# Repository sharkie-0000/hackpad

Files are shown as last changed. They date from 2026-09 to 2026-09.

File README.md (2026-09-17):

# My Hackpad

hey! this is my hackpad :)

i created this project to practice pcb design, electronics and firmware and at the same time create something i will be able to use on my desk.

the concept of this project is quite easy – small macropad with custom keys, rotary encoder and custom pcb. you can use it to set up your shortcuts, macros, control devices, etc.

## What is it

my hackpad has:

- 9 mechanical switches
- 1 rotary encoder
- XIAO RP2040
- 9 diodes
- 4 mounting holes
- custom PCB
- 3D printed case

i have built almost everything on my own so i would be able to understand the entire process of creating such device.

## Pictures / Files

### 3D Model
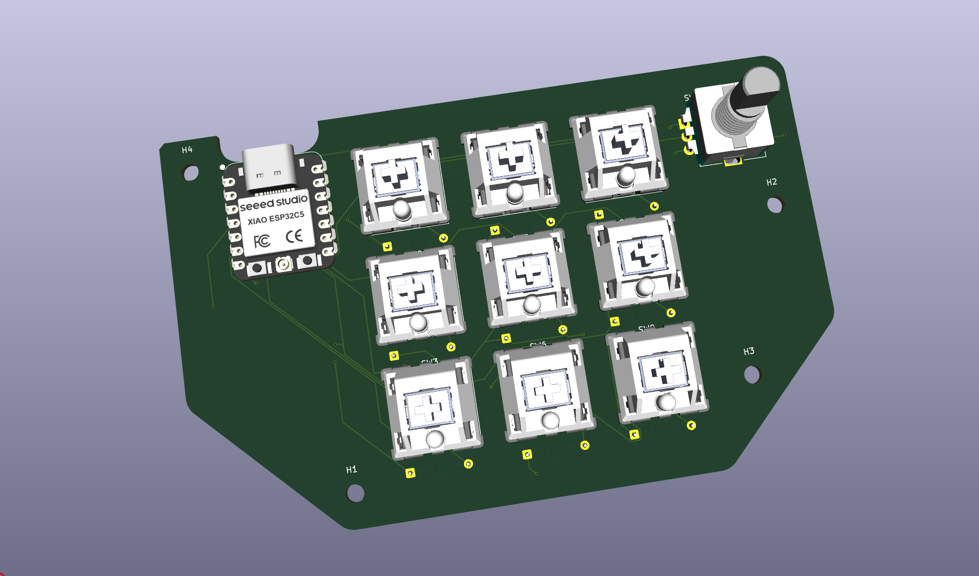
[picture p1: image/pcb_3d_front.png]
PCB 3D Front

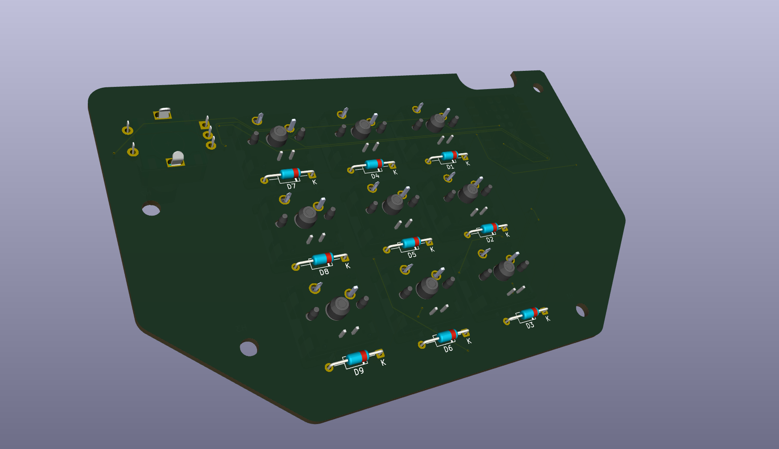
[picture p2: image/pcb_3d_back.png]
PCB 3D Back


### Circuit / Schematic
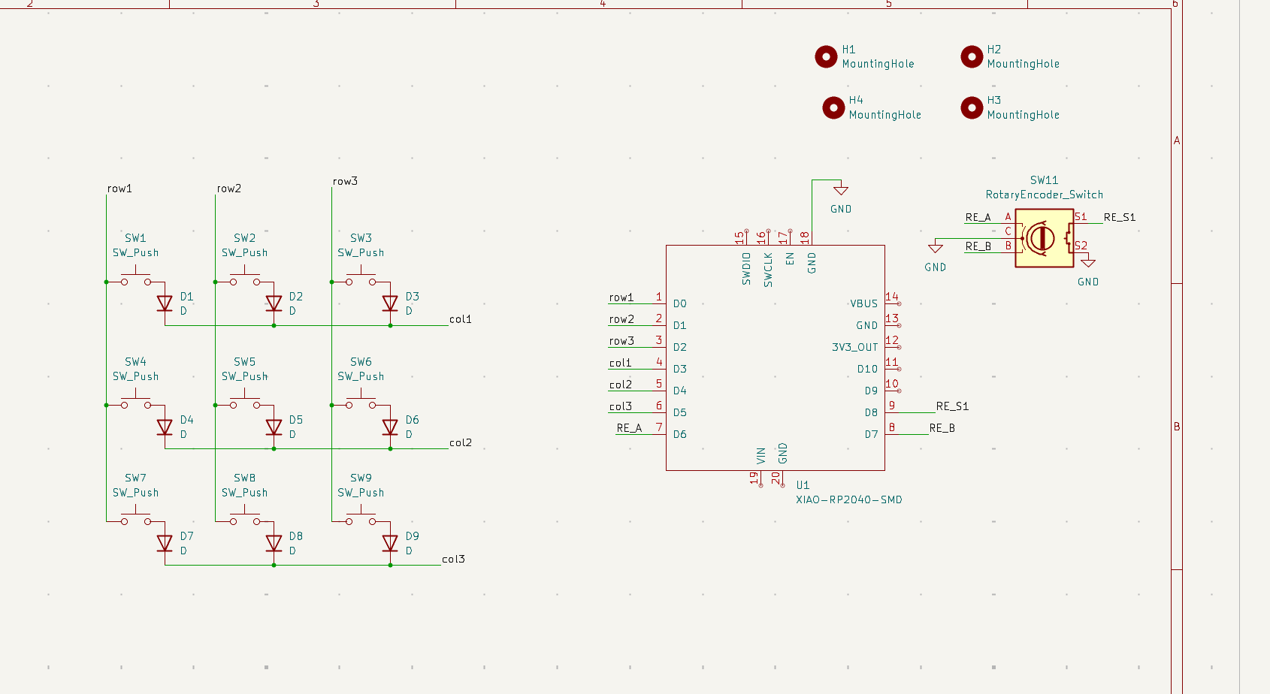
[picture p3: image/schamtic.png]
Schematic


### PCB Circuit
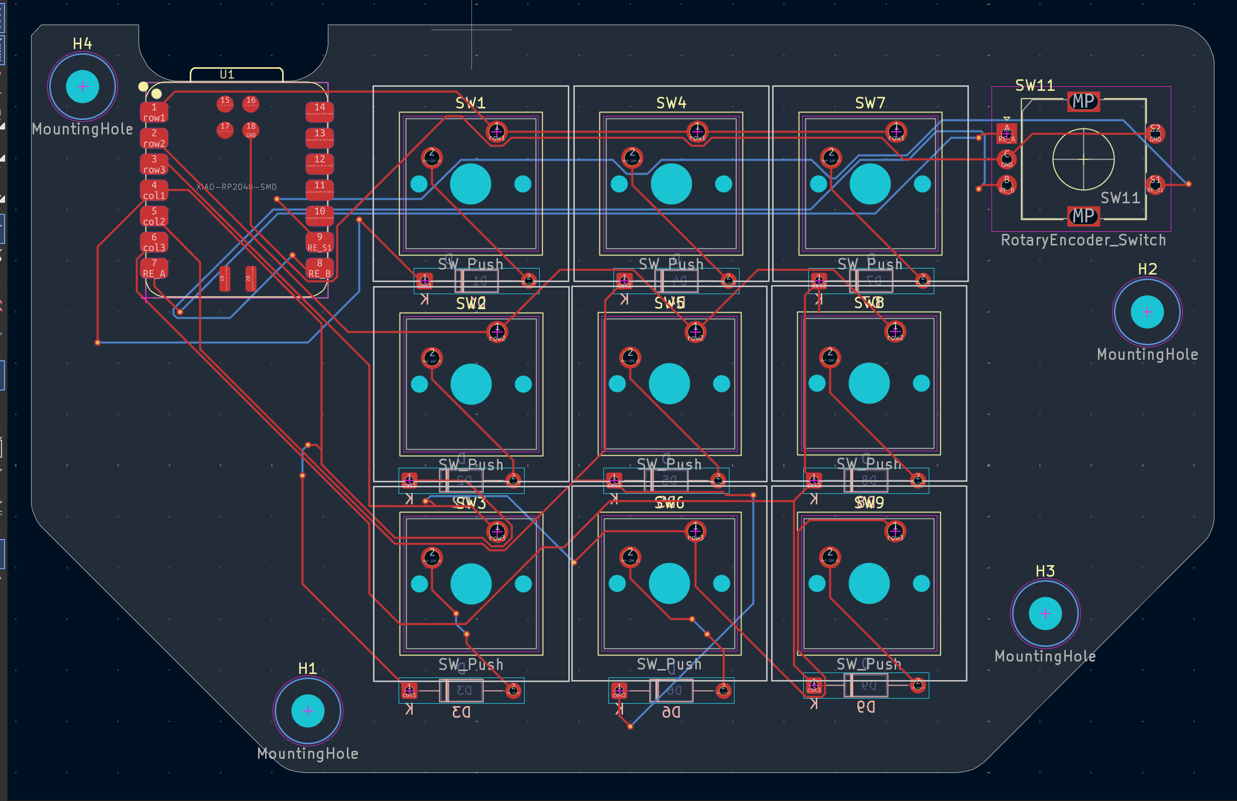
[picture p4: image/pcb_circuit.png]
PCB Circuit


## Bill of Materials (BOM)

here is the list of parts needed for the hackpad:

Here are the parts used for this build:

| Item | Quantity | Price | Link |
| --- | ---: | ---: | --- |
| Seeed Studio XIAO RP2040 Development Board | 1 | ₹589 | [Robu / RoboCraze](https://robocraze.com/products/seeed-studio-xiao-rp2040-development-board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) |
| Rotary Encoder (PEC12R-4225F-S0024) | 1 | ₹159 | [LionCircuits](https://www.lioncircuits.com/parts/PEC12R-4225F-S0024) |
| Cherry MX Mechanical Switches (Pack of 10) | 9 | ₹350 | [Cosmic Byte](https://www.thecosmicbyte.com/product/cherry-mx-mechancial-5-pin-switches-compatible-with-hot-swappable-keyboards-pack-of-10/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) |
| Spongebob Artisan Keycaps | 9 | ₹0 (already have) | [Meckeys](https://meckeys.com/shop/accessories/keyboard-accessories/keycaps/artisan-keycaps/spongebob-artisan-keycaps/) |
| PCB Fabrication | 1 | ₹720 | [JLCPCB](https://jlcpcb.com) |
| Diodes | 9 | ₹149 | [Diode](https://rees52.com/products/100pcs-diode-assortment-kit-rectifier-diode-kit-8-values-diy-electronic-diode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) |
| 3D Printed Case | 1 | — | — |
| **Total Cost** | | **₹1,967** | |

## Assembly Steps

1. Put the PCB on the bottom plate and fix it by using **M3 Screws**.
2. Fasten the upper portion of the box to the bottom plate with the help of **Glue**.
3. The use of M3 screws is **optional**. You can also fasten the whole box with the help of glue.
4. Ensure that everything is properly aligned.

## Why did i build this?

because i wanted to learn to create a circuit board myself rather than always purchasing them off the shelf. a custom macropad seemed to be an engaging way of learning and having something useful that i could use at my desk.

also built for Hack Club because it allowed me to engage in the process of building the circuit board from scratch without letting it stay only in my head.

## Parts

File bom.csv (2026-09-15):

Item | Price | Link
Seeed Studio XIAO RP2040 Development Board | ₹589 | https://robocraze.com/products/seeed-studio-xiao-rp2040-development-board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
Rotary Encoder (PEC12R-4225F-S0024) | ₹159 | https://www.lioncircuits.com/parts/PEC12R-4225F-S0024
Cherry MX Mechanical Switches (Pack of 10) | ₹350 | https://www.thecosmicbyte.com/product/cherry-mx-mechancial-5-pin-switches-compatible-with-hot-swappable-keyboards-pack-of-10/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
Spongebob Artisan Keycaps | ₹699 | https://meckeys.com/shop/accessories/keyboard-accessories/keycaps/artisan-keycaps/spongebob-artisan-keycaps/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
100pcs Diode Assortment Kit | ₹149.00 | "https://rees52.com/products/100pcs-diode-assortment-kit-rectifier-diode-kit-8-values-diy-electronic-diode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"
PCB Fabrication | USD 8.5 | https://jlcpcb.com

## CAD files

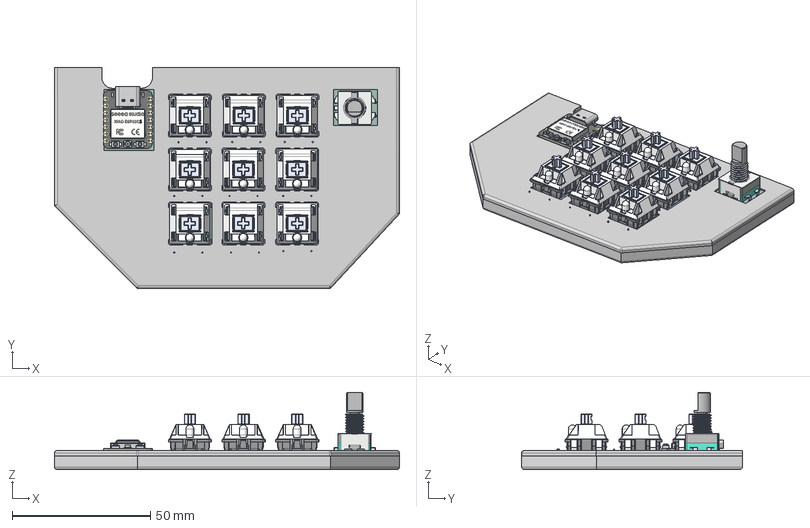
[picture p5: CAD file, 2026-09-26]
cad/hackpad-assembled.step
125.0 x 80.0 x 28.0 mm

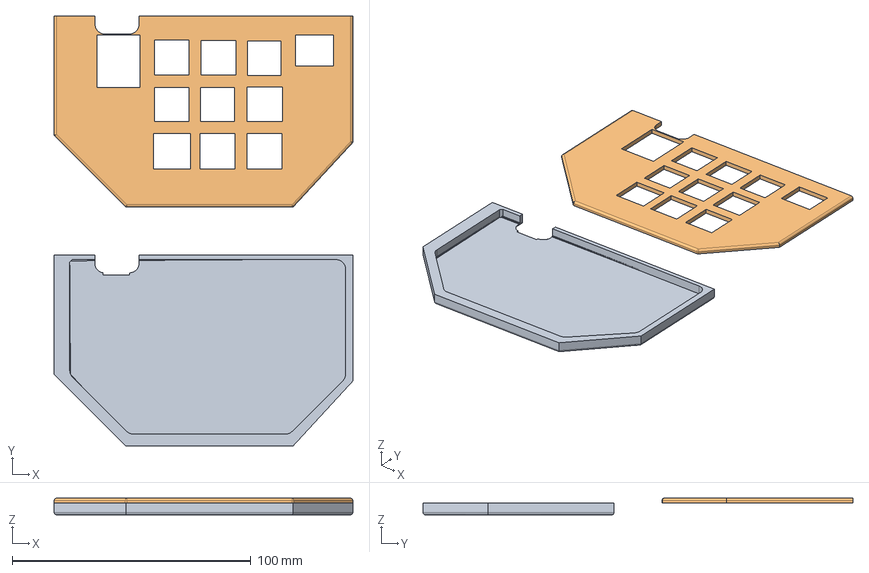
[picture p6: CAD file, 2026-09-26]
cad/hackpad-printable.step
125.0 x 180.0 x 7.00 mm

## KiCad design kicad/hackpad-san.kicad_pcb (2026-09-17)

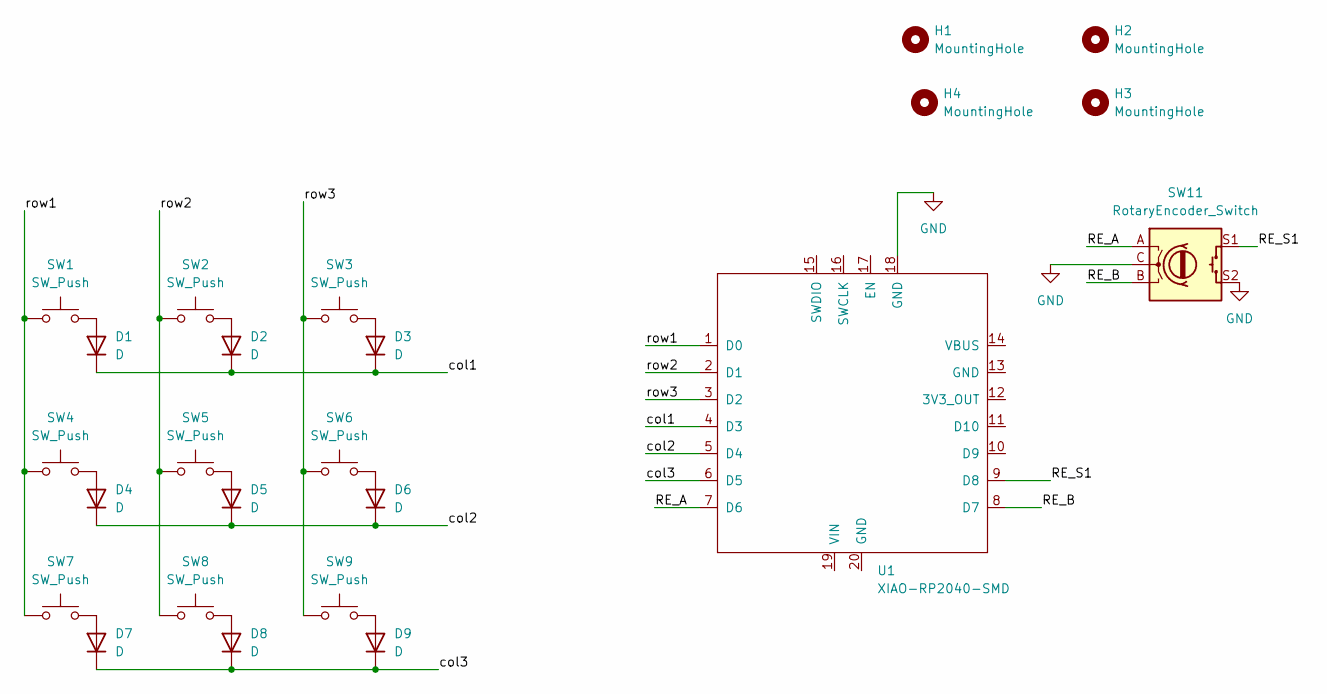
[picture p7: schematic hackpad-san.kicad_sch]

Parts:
D1, D2, D3, D4, D5, D6, D7, D8, D9: D; D_DO-35_SOD27_P10.16mm_Horizontal
H1, H2, H3, H4: MountingHole; MountingHole_3.2mm_M3
SW1, SW2, SW3, SW4, SW5, SW6, SW7, SW8, SW9: SW_Push; SW_Cherry_MX_1.00u_PCB
SW11: RotaryEncoder_Switch; RotaryEncoder_Alps_EC11E-Switch_Vertical_H20mm
U1: XIAO-RP2040-SMD

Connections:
/RE_A: SW11.A, U1.7 (D6)
/RE_B: SW11.B, U1.8 (D7)
/RE_S1: SW11.S1, U1.9 (D8)
/col1: D1.1 (K), D2.1 (K), D3.1 (K), U1.4 (D3)
/col2: D4.1 (K), D5.1 (K), D6.1 (K), U1.5 (D4)
/col3: D7.1 (K), D8.1 (K), D9.1 (K), U1.6 (D5)
/row1: SW1.1, SW4.1, SW7.1, U1.1 (D0)
/row2: SW2.1, SW5.1, SW8.1, U1.2 (D1)
/row3: SW3.1, SW6.1, SW9.1, U1.3 (D2)
GND: SW11.C, SW11.S2, U1.18 (GND)
unnamed: D1.2 (A), SW1.2
unnamed: D2.2 (A), SW2.2
unnamed: D3.2 (A), SW3.2
unnamed: D4.2 (A), SW4.2
unnamed: D5.2 (A), SW5.2
unnamed: D6.2 (A), SW6.2
unnamed: D7.2 (A), SW7.2
unnamed: D8.2 (A), SW8.2
unnamed: D9.2 (A), SW9.2

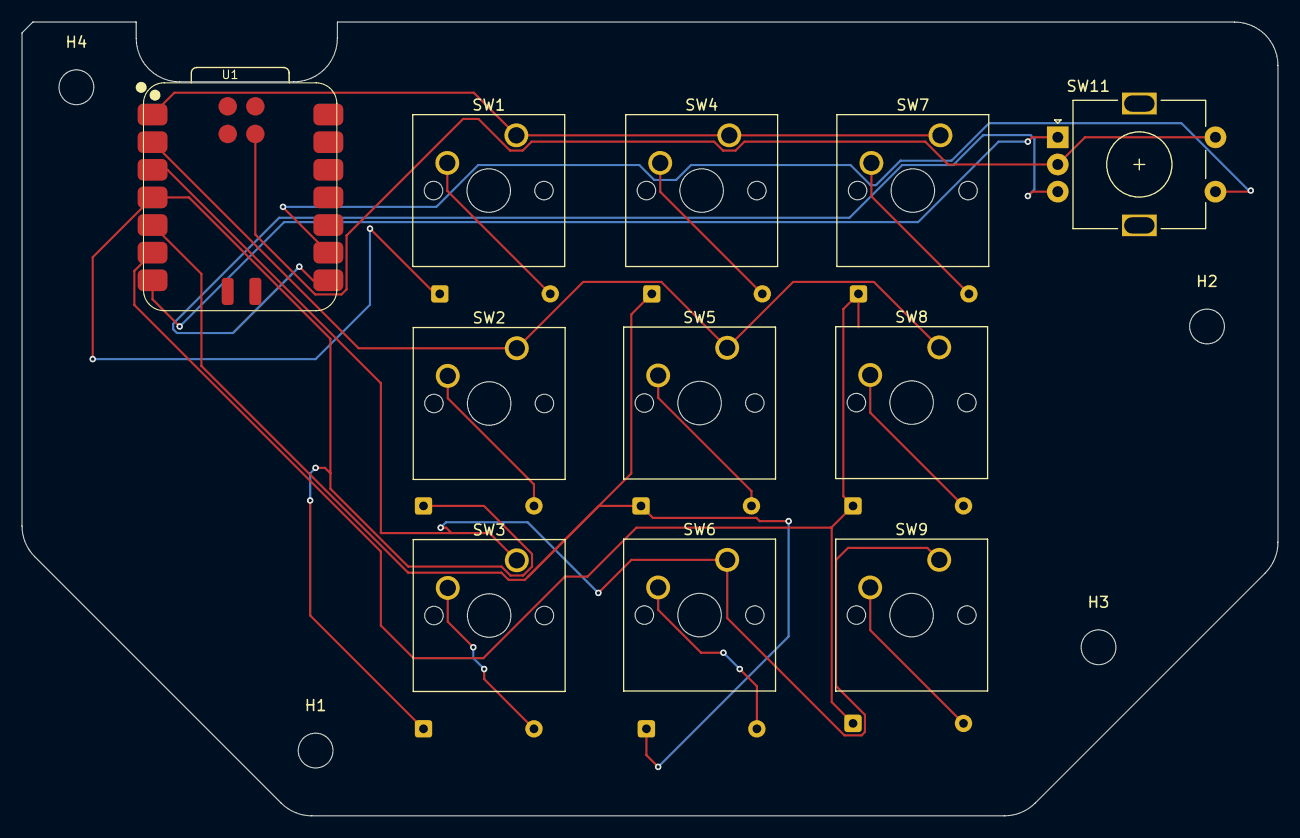
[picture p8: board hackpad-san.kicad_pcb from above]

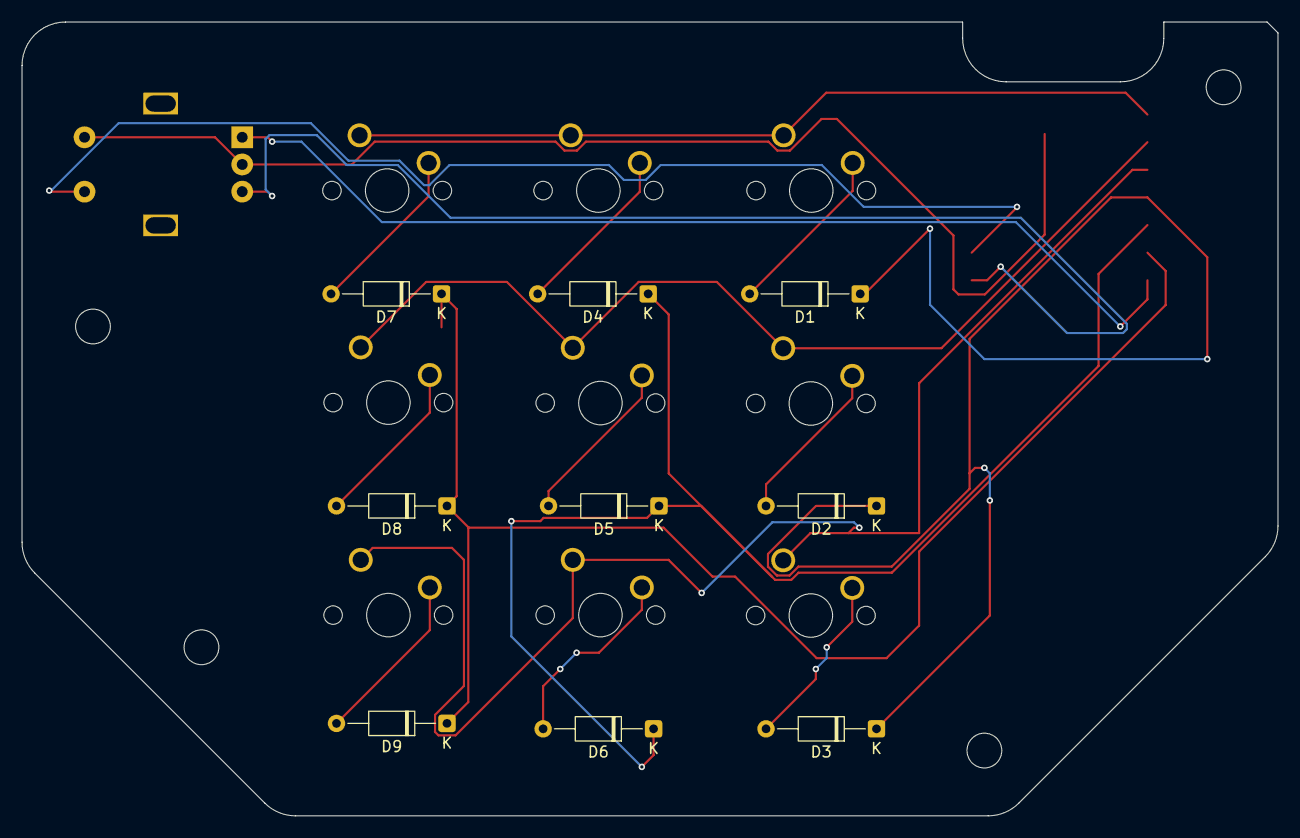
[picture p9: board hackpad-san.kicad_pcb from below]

Board: 2 copper layers, 115.5 x 73.0 mm, 24 parts (9 on the bottom side), 19 nets.

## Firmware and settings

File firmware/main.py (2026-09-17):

import board
import keypad
import rotaryio
import digitalio
import usb_hid
from adafruit_hid.keyboard import Keyboard
from adafruit_hid.keycode import Keycode
from adafruit_hid.consumer_control import ConsumerControl
from adafruit_hid.consumer_control_code import ConsumerControlCode

rows = (board.D0, board.D1, board.D2)
cols = (board.D3, board.D4, board.D5)

keys = keypad.KeyMatrix(rows, cols, columns_to_anodes=False)

keyboard = Keyboard(usb_hid.devices)
volume = ConsumerControl(usb_hid.devices)

keycodes = (
    Keycode.ONE, Keycode.TWO, Keycode.THREE,
    Keycode.FOUR, Keycode.FIVE, Keycode.SIX,
    Keycode.SEVEN, Keycode.EIGHT, Keycode.NINE
)

encoder = rotaryio.IncrementalEncoder(board.D6, board.D7)
last_position = encoder.position

button = digitalio.DigitalInOut(board.D8)
button.switch_to_input(pull=digitalio.Pull.UP)

while True:
    event = keys.events.get()

    if event:
        if event.pressed:
            keyboard.press(keycodes[event.key_number])
        elif event.released:
            keyboard.release(keycodes[event.key_number])

    position = encoder.position

    if position > last_position:
        volume.send(ConsumerControlCode.VOLUME_INCREMENT)
    elif position < last_position:
        volume.send(ConsumerControlCode.VOLUME_DECREMENT)

    last_position = position

    if not button.value:
        volume.send(ConsumerControlCode.MUTE)

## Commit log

2026-09-26 remove cad
    [hackpad.step]
2026-09-26 added cad files
    [hackpad-assembled.step, hackpad-printable.step]
2026-10-01 added more
    [hackpad-san.kicad_pcb]
2026-10-03 added kicad pcb file
    [hackpad-san.kicad_pcb]
